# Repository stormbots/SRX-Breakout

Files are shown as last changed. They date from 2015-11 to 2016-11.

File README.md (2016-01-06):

# Talon SRX Breakouts
Breakout circuit boards for easier wiring with the Talon SRX motor controller.

All source files are created using [CADSoft Eagle](http://www.cadsoftusa.com/download-eagle/). They can be uploaded by downloading the BRD files, and uploading them to a PCB fabrication service such as [OSHPark.com](http://oshpark.com)

- [SRX Dataport Breakout](SRX_Dataport_Breakout/): Provides a simple breakout to 0.1" servo headers for simpler wiring of inputs
   
- [SRX CAN Plugboard](SRX_CAN_Plugboard/): Provides a spring plug for the SRX for connecting to the CAN network, similar to the other 2015 control system devices.

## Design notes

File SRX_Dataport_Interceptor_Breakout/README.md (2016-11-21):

# Talon SRX Dataport Intercepter Breakout
This board breaks out the Talon SRX pins into a more easily usable 3-wire configuration that's compatible with standard servo cabling. This variant also includes a passthrough to the Gadgeteer port, allowing mixed usage of both 3 wire and Gadgeteer plug devices from [CTRE](http://www.ctr-electronics.com/). 

For additional configuration of the Talon SRX to take advantage of this board, see the [Talon SRX User's guide](http://content.vexrobotics.com/vexpro/pdf/Talon-SRX-User-Guide-20150201.pdf)

## Wiring
 The 4 3-wire connectors simply match servo cable order. Since switches generally don't care about voltage, all 3-wire signals use 3.3V. The voltage for the Analog Input Signal pin MUST be 3.3V in order to avoid damage to the Talon SRX.
 
 Connection Name | Pin 1 | Pin 2 | Pin 3 
 ---|---|---|---
Forward Limit Switch | GND |3.3V| Signal
Reverse Limit Switch | GND |3.3V| Signal
Quadrature Index Switch | GND |3.3V| Signal
Analog Input | GND |3.3V| Signal

The 4 wire quadrature encoder has a slightly different configuration. In addition, a solder jumper on the reverse side of the board allows for a configurable voltage. This is needed since some encoder boards require 5V signals, rather than the 3.3V.

Connection Name | Pin 1 | Pin 2 | Pin 3 |Pin 4
---|---|---|---|---
 Quadrature Encoder |GND | 3.3V or 5V |Signal A | Signal B

### Gadgeteer Pin Usage Chart
The Gadgeteer passthrough port works exactly as the one on the SRX does, with the same pinout and shroud orientation. 
Note, that compatibility issues will arise if both the Gadgeteer device and 3 wire device try to drive the same input line. This is called [bus contention](https://google.com/search?q=bus contention) and can result in incorrect operation or damage to your devices. 

This is not guaranteed to be complete, but may help assess what pins are available in combination with various other devices

Component                   |Analog |Fwd Limit| Rev Limit |Quad A | Quad B|
----------------------------|:-----:|:-------:|:---------:|:-----:|:-----:|
[CTRE Mag Encoder](http://www.ctr-electronics.com/srx-magnetic-encoder.html) |   Used   |         |           |  Used    |   Used   

[mag]: ""

## Bill Of Materials

Quantity | Description                  | Part Number |link
--------:|-----|------------------------|-------------|---
4        |  3-pin 0.1" header | Generic | [Digikey](http://www.digikey.com/product-detail/en/61300311121/732-5316-ND/4846825)
1        |  4-pin 0.1" header | Generic | [Digikey](http://www.digikey.com/product-detail/en/M20-9990445/952-2265-ND/3728229)
1        |  14-position 0.5" header | FCI 20021321-00014T4LF | [Digikey](https://www.digikey.com/product-detail/en/20021321-00014T4LF/609-3771-ND/2209082)
2        |  10k resistor (0603 package) | Generic | [Digikey](https://www.digikey.com/product-detail/en/RC0603JR-0710KL/311-10KGRCT-ND/729647)
2        |  Jumper wires | Generic 22 gauge wire  | 
1        | 10 pin 0.05" pitch shrouded socket | CNC Tech 3220-10-0100-00| [Digikey](http://www.digikey.com/product-detail/en/3220-10-0100-00/1175-1627-ND/3883661) 

## Assembly
1. Assemble the surface mount components to the bottom of the board
2. Solder the jumper to select the voltage for the quadrature encoder. 
3. Attach the wire jumpers. These jumpers only work as spacers between the Talon SRX and the PCB. This helps stabilize the connector, and prevent shorting against the 0.1" headers.
4. Attach the 0.1" headers so they face away from the body of the Talon SRX
4. Optionally, attach the 0.05" header so they face away from the body of the Talon SRX
5. Place a piece of electrical tape over the bottom of the board, covering the 0.1" headers, resistors, and solder jumpers.

## Mounting 
1. Remove the screws on the Talon SRX
2. Gently connect the backside connector to the Talon SRX. 
3. Re-insert the screws, and tighten gently. Do not use excessive force*

*  _Using significant force on the screws can damage the Talon SRX. It can also cause the 0.1" joints to punch through the electrical tape, causing signal errors or power shorting. The jumper wires will help provide spacing to prevent these issues._

## FRC Technicalities
This is a passive wiring board, and contains no active components.

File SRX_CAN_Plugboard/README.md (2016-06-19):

# SRX CAN Plugboard
Provides a spring plug for the SRX for connecting to the CAN network, similar to the other 2015 control system devices. This enables you to cut the wires shorter, and use Ferrule terminators instead of splicing.

## Assembly
No special notes. Simply solder components to the board. 

## Mounting
Can be mounted with either screws or zip ties. Mounting holes and zip tie indents are spaced 1" apart on either side of the connector.

This cannot be mounted directly on conductive surfaces. Doing so will likely short the CAN connections, halting the robot. It's suggested to add a wood block or other spacer when mounting on a surface that may cause the pins to short.

## FRC Technicalities
This is a passive wiring board, and contains no active components.

## Bill Of Materials
Quantity | Description                  | Part Number |link
--------:|-----|------------------------|-------------|---
4        |  2 slot vertical spring mount| Weidmuller 1825960000 | [Digikey](http://www.digikey.com/product-detail/en/1825960000/281-2124-ND/1094462)

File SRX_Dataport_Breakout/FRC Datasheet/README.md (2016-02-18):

# Talon SRX Dataport Breakout
 
# Description
This board breaks out the Talon SRX pins into a more easily usable 3-wire configuration that's compatible with standard servo cabling.

# FRC Regulations
This is a passive device

#Schematic
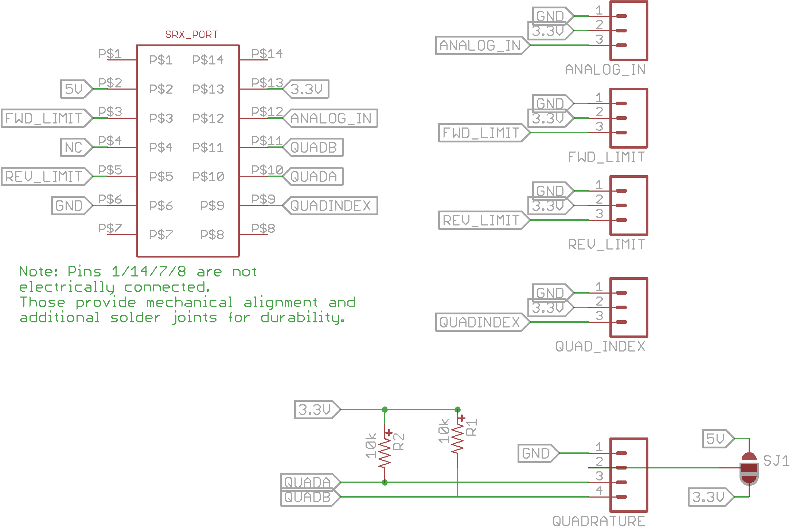
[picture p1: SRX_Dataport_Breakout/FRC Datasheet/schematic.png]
Schematic Layout


#PCB Top
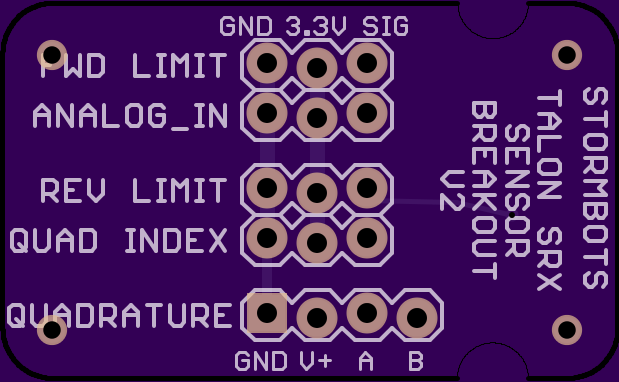
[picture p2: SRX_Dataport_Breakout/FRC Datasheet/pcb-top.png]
PCB Top Side
 

#PCB Bottom!
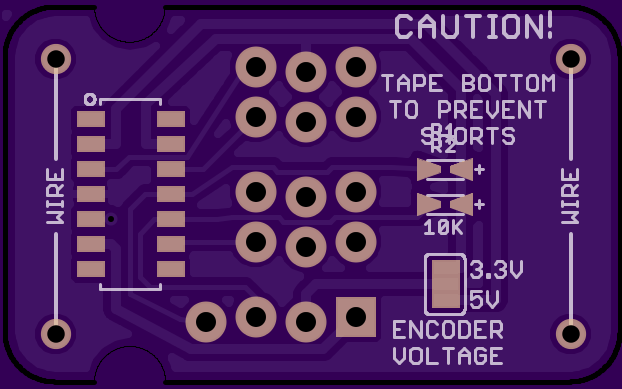
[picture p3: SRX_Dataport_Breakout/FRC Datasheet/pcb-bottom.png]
PCB Bottom Side


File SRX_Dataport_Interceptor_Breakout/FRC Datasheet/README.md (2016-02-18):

# Talon SRX Dataport Breakout with passthrough
 
# Description
This board breaks out the Talon SRX pins into a more easily usable 3-wire configuration that's compatible with standard servo cabling.

This version also includes a 1-1 passthrough for use with existing Gadgeteer devices by CTRE

# FRC Regulations
This is a passive device

#Schematic
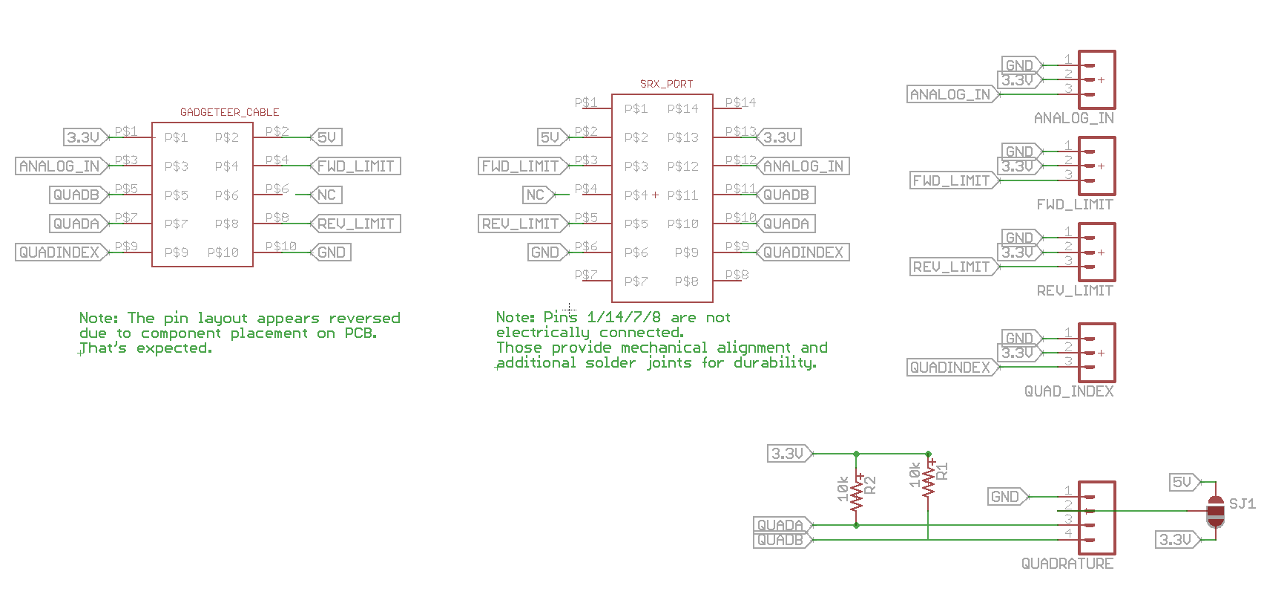
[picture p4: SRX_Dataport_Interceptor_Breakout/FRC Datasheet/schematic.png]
Schematic Layout


#PCB Top
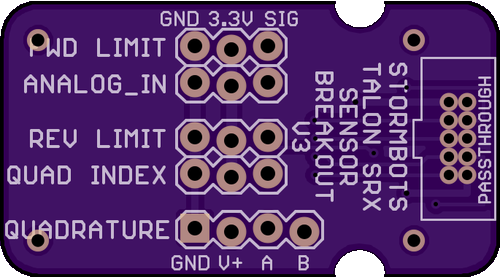
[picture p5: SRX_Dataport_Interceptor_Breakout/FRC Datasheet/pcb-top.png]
PCB Top Side
 

#PCB Bottom!
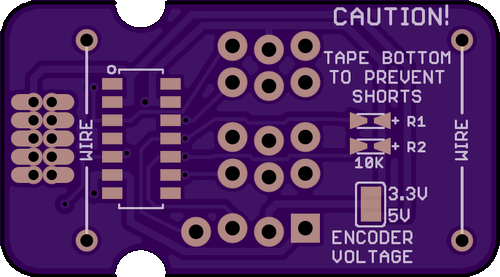
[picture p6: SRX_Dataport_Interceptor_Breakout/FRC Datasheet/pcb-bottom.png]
PCB Bottom Side


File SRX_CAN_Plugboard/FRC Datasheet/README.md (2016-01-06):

# SRX CAN Plugboard
 
# Description
Provides a spring plug for the SRX for connecting to the CAN network, similar to the other 2015 control system devices

# FRC Regulations
This is a passive device

#Schematic
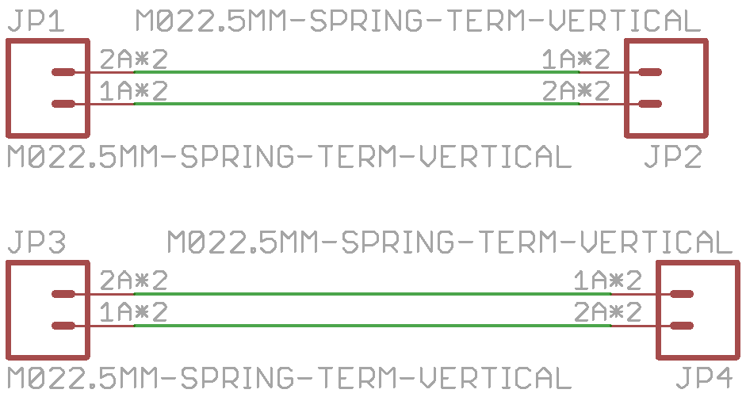
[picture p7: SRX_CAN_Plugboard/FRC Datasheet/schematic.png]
Schematic Layout


#PCB Top
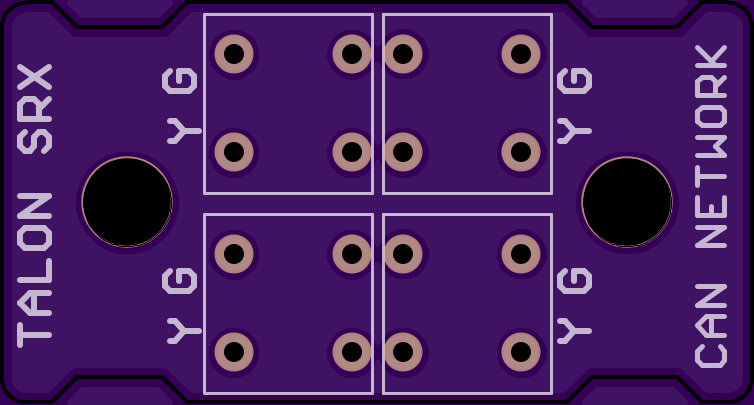
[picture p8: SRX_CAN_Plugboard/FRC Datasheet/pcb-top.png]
PCB Top Side


#PCB Bottom!
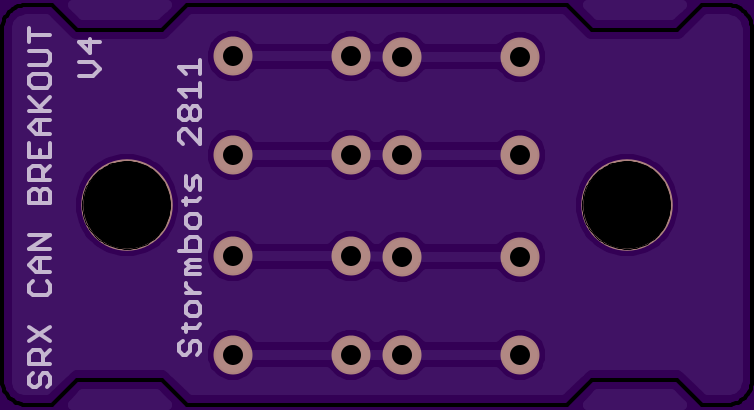
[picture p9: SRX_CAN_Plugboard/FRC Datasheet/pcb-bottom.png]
PCB Bottom Side


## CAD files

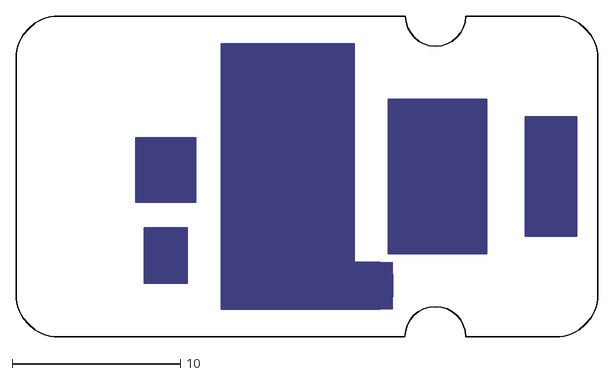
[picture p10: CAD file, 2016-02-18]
SRX_Dataport_Interceptor_Breakout/SRX-dataport-interceptor-breakout.dxf
34.5 x 19.1

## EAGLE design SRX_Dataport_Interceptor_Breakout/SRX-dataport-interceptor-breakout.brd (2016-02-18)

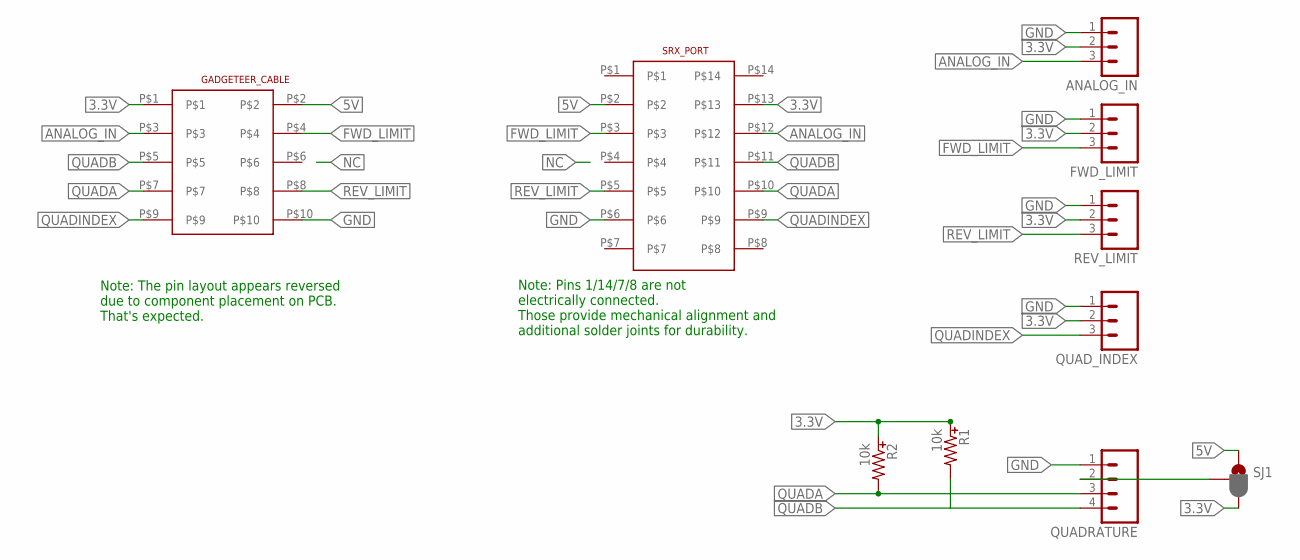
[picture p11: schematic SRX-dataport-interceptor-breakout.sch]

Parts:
ANALOG_IN: M03LOCK; 1X03_LOCK
FWD_LIMIT: M03LOCK; 1X03_LOCK
GADGETEER_CABLE: M05X02M_SHROUDED; M2X05_M_SHROUDED
QUADRATURE: M04LOCK; 1X04_LOCK
QUAD_INDEX: M03LOCK; 1X03_LOCK
R1, R2: 10k; 0402-0603-0805-UNIVERSAL
REV_LIMIT: M03LOCK; 1X03_LOCK
SJ1: JUMPER-PAD-3-2OF3_NC_BY_PASTE; PAD-JUMPER-3-2OF3_NC_BY_PASTE_YES_SILK_FULL_BOX
SRX_PORT: M07X0220021321-00014TFLF; M2X07_SMD

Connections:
3.3V: ANALOG_IN.2, FWD_LIMIT.2, GADGETEER_CABLE.P$1, QUAD_INDEX.2, R1.+ (1), R2.+ (1), REV_LIMIT.2, SJ1.3, SRX_PORT.P$13
5V: GADGETEER_CABLE.P$2, SJ1.1, SRX_PORT.P$2
ANALOG_IN: ANALOG_IN.3, GADGETEER_CABLE.P$3, SRX_PORT.P$12
FWD_LIMIT: FWD_LIMIT.3, GADGETEER_CABLE.P$4, SRX_PORT.P$3
GND: ANALOG_IN.1, FWD_LIMIT.1, GADGETEER_CABLE.P$10, QUADRATURE.1, QUAD_INDEX.1, REV_LIMIT.1, SRX_PORT.P$6
QUADA: GADGETEER_CABLE.P$7, QUADRATURE.3, R2.- (2), SRX_PORT.P$10
QUADB: GADGETEER_CABLE.P$5, QUADRATURE.4, R1.- (2), SRX_PORT.P$11
QUADINDEX: GADGETEER_CABLE.P$9, QUAD_INDEX.3, SRX_PORT.P$9
QUAD_VOLTAGE: QUADRATURE.2, SJ1.2
REV_LIMIT: GADGETEER_CABLE.P$8, REV_LIMIT.3, SRX_PORT.P$5

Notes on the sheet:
Note: Pins 1/14/7/8 are not electrically connected. Those provide mechanical alignment and additional solder joints for durability.
Note: The pin layout appears reversed due to component placement on PCB. That's expected.

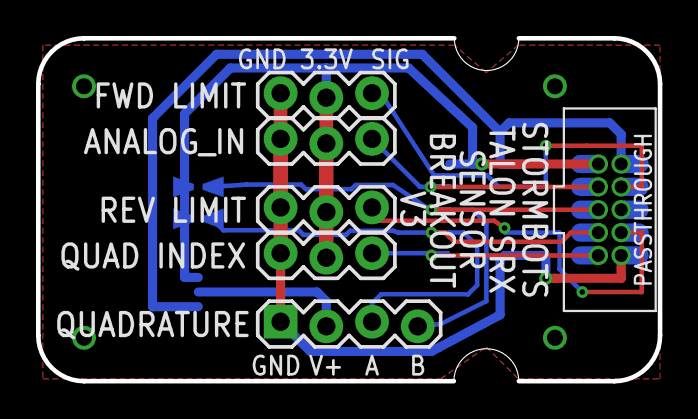
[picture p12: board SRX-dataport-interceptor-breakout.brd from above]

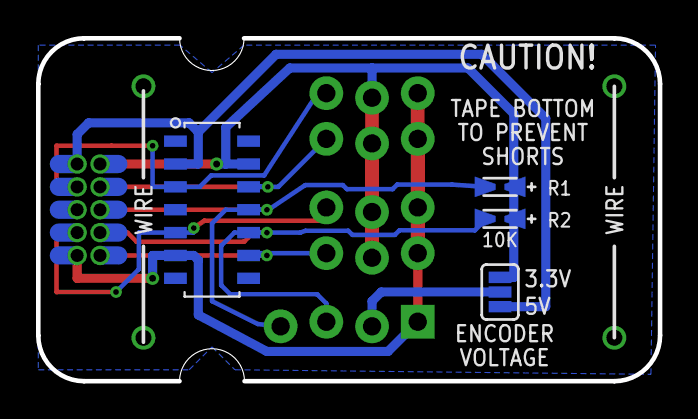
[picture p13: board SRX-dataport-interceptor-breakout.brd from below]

Board: 2 copper layers, 34.5 x 19.1 mm, 11 parts (4 on the bottom side), 10 nets.

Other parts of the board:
U$1: TALONSRX

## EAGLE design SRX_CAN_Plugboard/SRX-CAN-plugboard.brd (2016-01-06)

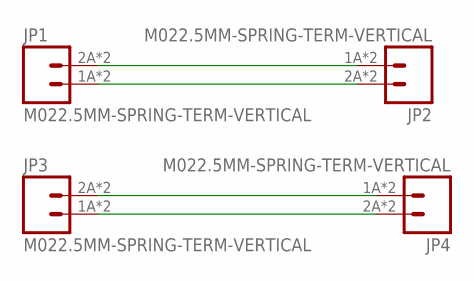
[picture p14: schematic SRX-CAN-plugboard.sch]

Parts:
JP1, JP2, JP3, JP4: M022.5MM-SPRING-TERM-VERTICAL; 1824740000-2X-VERTICAL-SPRING-TERMINAL

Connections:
unnamed: JP3.2A (2), JP3.2B (2), JP4.1A (1), JP4.1B (1)
unnamed: JP3.1A (1), JP3.1B (1), JP4.2A (2), JP4.2B (2)
unnamed: JP1.1A (1), JP1.1B (1), JP2.2A (2), JP2.2B (2)
unnamed: JP1.2A (2), JP1.2B (2), JP2.1A (1), JP2.1B (1)

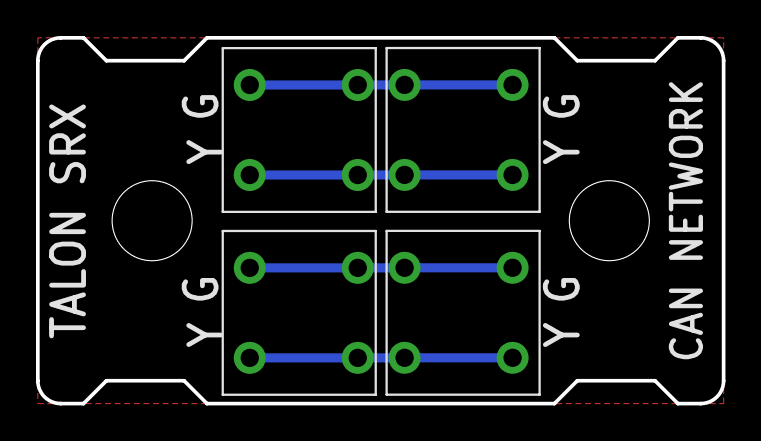
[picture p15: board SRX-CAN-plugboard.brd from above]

Board: 2 copper layers, 38.1 x 20.3 mm, 4 parts (0 on the bottom side), 4 nets.

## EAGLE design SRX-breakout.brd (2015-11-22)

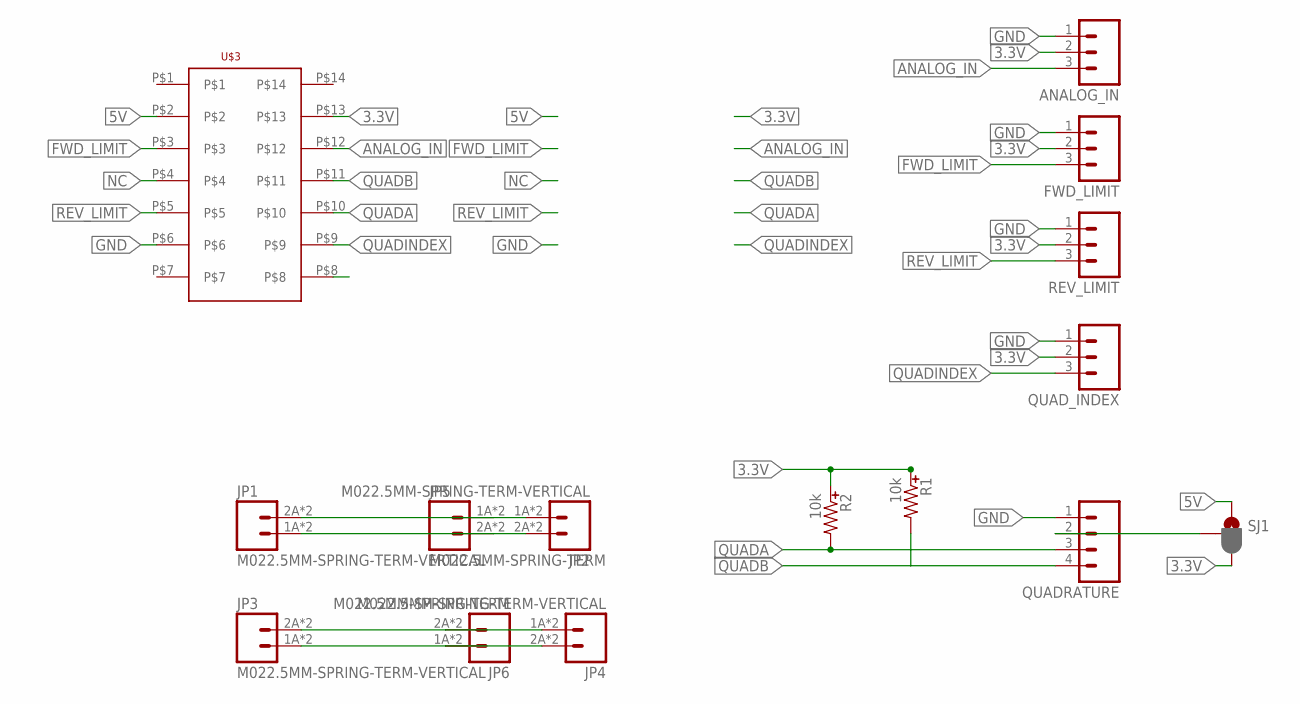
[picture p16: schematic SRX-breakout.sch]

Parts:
ANALOG_IN: M03LOCK; 1X03_LOCK
FWD_LIMIT: M03LOCK; 1X03_LOCK
JP1, JP2, JP3, JP4: M022.5MM-SPRING-TERM-VERTICAL; 1824740000-2X-VERTICAL-SPRING-TERMINAL
JP5, JP6: M022.5MM-SPRING-TERM; 1824740000-2X-STRAIGHT-SPRING-TERMINAL
QUADRATURE: M04LOCK; 1X04_LOCK
QUAD_INDEX: M03LOCK; 1X03_LOCK
R1, R2: 10k; 0402-0603-0805-UNIVERSAL
REV_LIMIT: M03LOCK; 1X03_LOCK
SJ1: JUMPER-PAD-3-2OF3_NC_BY_PASTE; PAD-JUMPER-3-2OF3_NC_BY_PASTE_YES_SILK_FULL_BOX
U$3: M07X0220021321-00014TFLF; M2X07_SMD

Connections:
3.3V: ANALOG_IN.2, FWD_LIMIT.2, QUAD_INDEX.2, R1.+ (1), R2.+ (1), REV_LIMIT.2, SJ1.3, U$3.P$13
5V: SJ1.1, U$3.P$2
ANALOG_IN: ANALOG_IN.3, U$3.P$12
FWD_LIMIT: FWD_LIMIT.3, U$3.P$3
GND: ANALOG_IN.1, FWD_LIMIT.1, QUADRATURE.1, QUAD_INDEX.1, REV_LIMIT.1, U$3.P$6
unnamed: JP3.2A (2), JP3.2B (2), JP4.1A (1), JP4.1B (1), JP6.2A (1), JP6.2B (1)
unnamed: JP3.1A (1), JP3.1B (1), JP4.2A (2), JP4.2B (2), JP6.1A (2), JP6.1B (2)
unnamed: JP1.1A (1), JP1.1B (1), JP2.2A (2), JP2.2B (2), JP5.2A (1), JP5.2B (1)
unnamed: JP1.2A (2), JP1.2B (2), JP2.1A (1), JP2.1B (1), JP5.1A (2), JP5.1B (2)
NC: U$3.P$4
QUADA: QUADRATURE.3, R2.- (2), U$3.P$10
QUADB: QUADRATURE.4, R1.- (2), U$3.P$11
QUADINDEX: QUAD_INDEX.3, U$3.P$9
QUAD_VOLTAGE: QUADRATURE.2, SJ1.2
REV_LIMIT: REV_LIMIT.3, U$3.P$5

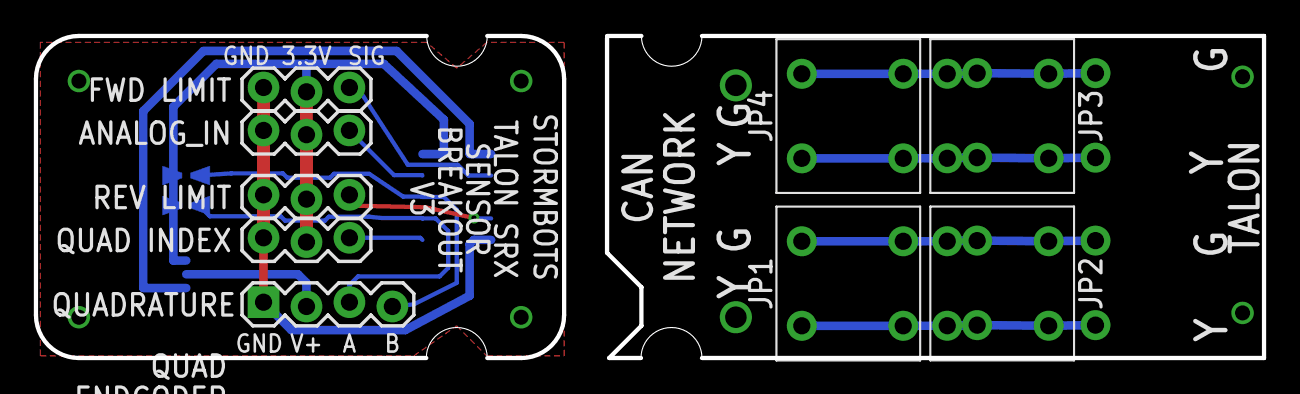
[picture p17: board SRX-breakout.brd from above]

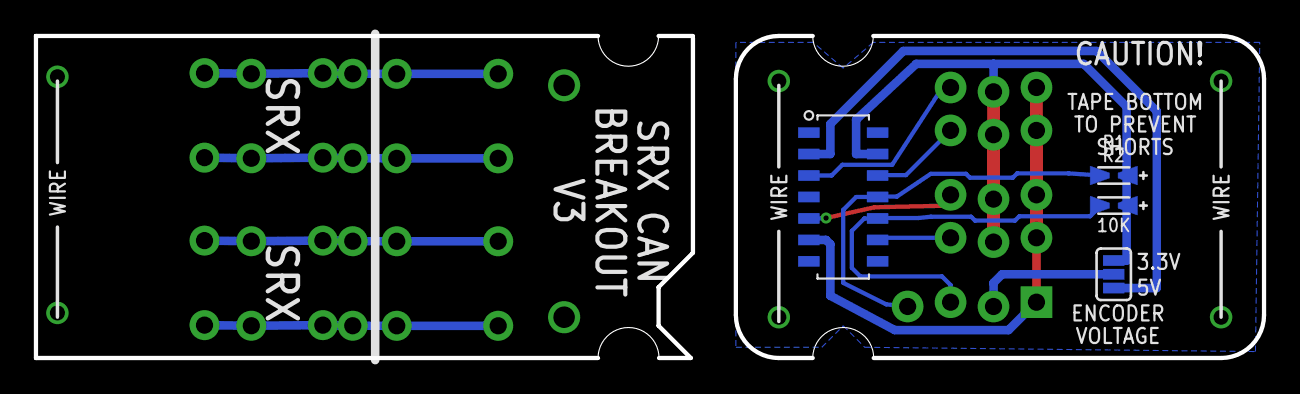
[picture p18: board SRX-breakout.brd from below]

Board: 2 copper layers, 72.6 x 19.1 mm, 16 parts (4 on the bottom side), 14 nets.

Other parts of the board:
U$1: TALONSRX

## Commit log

2015-11-09 Init with V2 boards
    [SRX-breakout.brd, SRX-breakout.sch]
2015-11-09 Updated mechanical drawing of SRX
    [SRX-breakout.brd, SRX-breakout.sch]
2015-11-09 Add CAN subboard
    [SRX-breakout.brd, SRX-breakout.sch]
2015-11-22 Minor adjustments for mechanical purposes
    [SRX-breakout.brd]
2016-01-06 Add documentation
    [SRX-CAN-plugboard.brd, SRX-CAN-plugboard.sch, SRX-dataport-breakout.brd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]
2016-02-18 Add SRX breakout with passthrough
    [SRX-dataport-interceptor-breakout.brd, SRX-dataport-interceptor-breakout.dxf, SRX-dataport-interceptor-breakout.sch]
2016-02-18 Fixed text to represent the correct board

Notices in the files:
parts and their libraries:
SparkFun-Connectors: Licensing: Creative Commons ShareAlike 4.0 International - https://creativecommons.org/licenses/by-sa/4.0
